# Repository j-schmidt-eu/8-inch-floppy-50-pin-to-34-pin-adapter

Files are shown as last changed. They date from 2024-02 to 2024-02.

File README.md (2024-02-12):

# 8-inch floppy drive - 50-pin to 34-pin adapter Rev. 2

> The 50-pin to 34-pin adapter can be used to adapt 8-inch floppy disk drives (using a 50-pin connector) to be controlled by 3.5-inch and 5.25-inch floppy controllers (using a 34-pin connector).

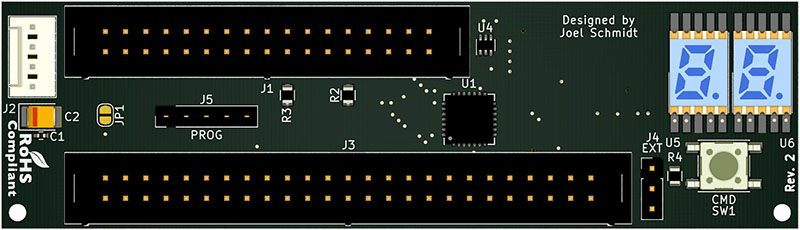
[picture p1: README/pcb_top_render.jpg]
PCB top render


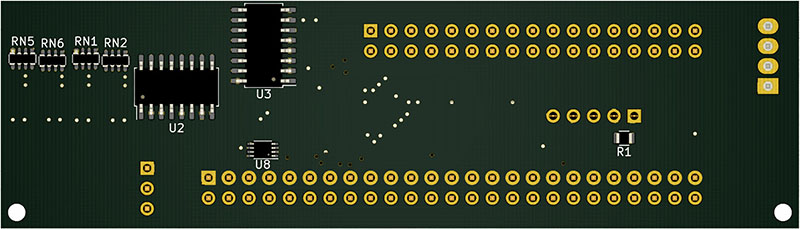
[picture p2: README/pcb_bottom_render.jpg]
PCB bottom render


## Table of Contents
- [Introduction](#Introduction)
- [Specifications](#Specifications)
- [Setup](#Setup)
- [Operation](#Operation)
- [Compatibility](#Compatibility)
- [Manufacturing](#Manufacturing)
- [Firmware](#Firmware)
- [FAQ](#FAQ)
- [Licensing](#Licensing)

## Introduction
Many 8-inch floppy drives use a 50-pin card-edge connector to link them to a controller. This is a problem, since modern floppy controllers use a 34-pin IDC connector.
To solve this problem an adapter is necessary that connects compatible signals and generates signals that are unique to the 8-inch floppy drives.
This project aims to provide the schematic, PCB design and firmware source code to build such an adapter.
All compatible signals are directly linked from the 50-pin connector to the 34-pin connector.
Other signals are generated with an onboard microcontroller.

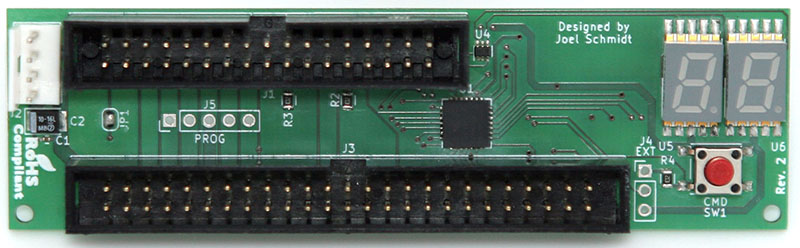
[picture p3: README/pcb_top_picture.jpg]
PCB top picture


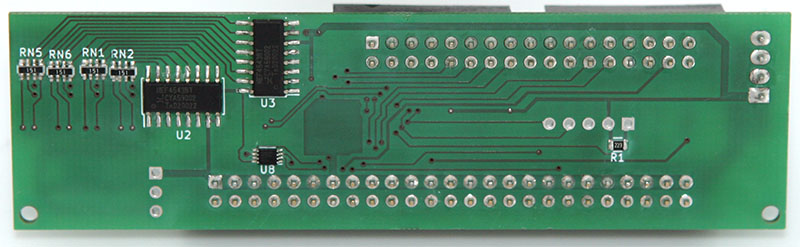
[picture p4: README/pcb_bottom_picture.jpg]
PCB bottom picture


## Specifications
- Power
  - Input voltage: 5V DC
  - Maximum input current: 750mA
  - Connector: 4-pin Berg/Amphenol
- Maximum number of drives per adapter: 2
- Maximum number of adapters per controller: 1
- Pass-through signals:

  | Direction | Name |
  | --------- | ---- |
  | IN        | Index |
  | OUT       | Drive select A |
  | OUT       | Drive select B |
  | OUT       | Direction |
  | OUT       | Step |
  | OUT       | Write data |
  | OUT       | Write gate |
  | IN        | Track 0 |
  | IN        | Write protect |
  | IN        | Read data |
  | OUT       | Side select |
- Generated signals:

  | Direction | Name | Signal source |
  | --------- | ---- | ------------- |
  | OUT       | TG43 (Track greater than 43) /<br>Reduce write current /<br>Filter switch | Determined by tracking the head position.<br>Multiple options available (e.g. control via external signal) |
  | OUT       | Head load | Derived from Motor enable signal.<br>Multiple options available (e.g. control via external signal) |
  | IN        | Ready | Derived from ready signal.<br>Can be disabled by removing a solder jumper bridge JP1 |

## Setup
The adapter can drive up to two drives.

### Floppy drive
A single drive should always be jumpered to be drive A.
The drive should have the termination resistors enabled/present.

A two drive setup should have one drive jumpered to be drive A and the other to be drive to be jumpered drive B.
The last drive (the drive connected at the end of the 50-pin ribbon cable) should have the termination resistors enabled/present, the other drive must have the termination resistors disabled/removed.

__**Important: Only one set of termination resistors must be enabled/present! Having more than one termination resistors enabled/present can damage the adapter and the floppy controller!**__

### Connections

#### Data
To connect the controller to the adapter, use a 34-pin ribbon cable (IDC socket connector to IDC socket connector).
It is recommended to connect the adapter after the twist in the ribbon cable. 

_Note: **When using straight cable without twist, drive A and drive B will be swapped on the controller side.**_

The drive(s) should be connected to the adapter with a 50-pin ribbon cable (IDC card edge connector to IDC socket connector).

#### Power
The adapter should be connected to a power supply via the 4 pin Berg/Amphenol connector (only the 5V line will be used). The pinout is ATX compatible.
Power for the floppy drive(s) should be supplied as described in the operations manual for that specific drive.

## Operation
To operate the adapter a single push button (command button) is present on the bottom right corner of the PCB.

_Note: **The button will be disabled when any drive is in use.**_

### Display
For status display and settings, a two-digit seven-segment display is present on the top right corner of the PCB.
A short press on the command button can be used to cycled between the following display modes:

| Mode | Dot status | Description | Range |
| ---- | ---- | --- | ----- |
| Track | Left: off<br>Right: on | Current head position | 0 ... 80 |
| Speed | Left: on (positive value) / blink (negative value)<br>Right: off | Percent deviation from nominal rotational speed | -9.9% ... 9.9% |
| Revision | Left: blink<br>Right: blink<br>Alternates between left and right | Software revision number | 1 ... 99 |
| Dark | Left: off<br>Right: off | Disables display | - |

### Settings
To edit the settings of the adapter the setup menu can be entered by pressing the command button for longer than two seconds.
When navigating the setup menu both dots will be lit.
A short press on the command button can be used to cycled between the menu items.
Item value editing can be enabled and disabled by pressing the command button for longer than two seconds.
During editing both dots will blink simultaneously.
A short press on the command button can be used to cycled between value.

To exit the setup menu, navigate to the Exit item and press the command button for longer than two seconds.

The following menu items are available (in listed order):

| Item | Display | Description | Values | Default |
| ---- | --- | --- | --- | --- |
| Default display mode | Left: 1<br>Right: value | Default display mode after adapter power up | 0: Track<br>1: Speed<br>2: Revision<br>3: Dark | 0: Track |
| Drive A<br>Maximum track number | Left/Right: value | Maximum track number that the drive can step to | 32 ... 80 | 76 |
| Drive A<br>TGxx signal | Left: 3<br>Right: value | Source for TG43 / reduce write current / filter signal | 0: Use thresholds<br>1: Always active<br>2: Always inactive<br>3: From external signal | 0: Use thresholds |
| Drive A<br>Head load signal | Left: 4<br>Right: value | Source for head load signal | 0: From [motor A enable]<br>1: Always active<br>2: Always inactive<br>3: From external signal | 0: From [motor A enable] |
| Drive A<br>TGxx write threshold | Left/Right: value | Track number threshold (greater or equal) for TGxx signal active when writing | 0 ... 99 | 44 |
| Drive A<br>TGxx read threshold | Left/Right: value | Track number threshold (greater or equal) for TGxx signal active when reading | 0 ... 99 | 99 |
| Drive B<br>Maximum track number | Left/Right: value | Maximum track number that the drive can step to | 32 ... 80 | 76 |
| Drive B<br>TGxx signal | Left: 8<br>Right: value | Source for TG43 / reduce write current / filter signal | 0: Use thresholds<br>1: Always active<br>2: Always inactive<br>3: From external signal | 0: Use thresholds |
| Drive B<br>Head load signal | Left: 9<br>Right: value | Source for head load signal | 0: From [motor B enable]<br>1: Always active<br>2: Always inactive<br>3: From external signal | 0: From [motor B enable] |
| Drive B<br>TGxx write threshold | Left/Right: value | Track number threshold (greater or equal) for TGxx signal active when writing | 0 ... 99 | 44 |
| Drive B<br>TGxx read threshold | Left/Right: value | Track number threshold (greater or equal) for TGxx signal active when reading | 0 ... 99 | 99 |
| Exit | Left/Right: dark | - | - | - |

_Note: **The external signal cannot distinguish between multiple signals, therefore it should only be assigned to a single signal.**_

The settings are permanently stored when exiting the setup menu.

## Compatibility
The following list shows some 8-inch floppy drive models and the respective settings that should be correct for them.

| Model | TGxx signal | TGxx write threshold | TGxx read threshold | Head load signal | Maximum track number<sup>1</sup> | Tested<sup>2</sup> |
| ----- | --- | --- | --- | --- | --- | --- |
| Mitsubishi M2896-63 | 0: Use thresholds <sup>4</sup> | 44 | 99 | 0: From [motor enable]  | 76(?) | ❓ |
| NEC FD1165 | 0: Use thresholds | 44 | 44 | 0: From [motor enable] | 76(?) | ❓ |
| Shugart SA800<br>Shugart SA801 | 0: Use thresholds <sup>3</sup> | 44 | 99 | 0: From [motor enable] <sup>4</sup> | 76(?) | ❓ |
| Shugart SA810<br>Shugart SA860 | 0: Use thresholds <sup>4</sup> | 44 | 99 | 0: From [motor enable] <sup>4</sup> | 76(?) | ❓ |
| Shugart SA850<br>Shugart SA851 | 0: Use thresholds <sup>4</sup> | 44 | 99 | 0: From [motor enable] <sup>4</sup> | 76(?) | ❓ |
| Tandon TM848-1E<br>Tandon TM848-2E | 0: Use thresholds <sup>4</sup> | 44 | 99 | 0: From [motor enable] <sup>4</sup> | 76(?) | ❓ |
| Y-E DATA YD-180 | 0: Use thresholds | 44 | 60 | 0: From [motor enable] <sup>4</sup> | 79 | ✅ |

<sup>1</sup> Actual seekable track number; track numbering starts at zero.<br>
<sup>2</sup> ✅: Settings have been successfully tested. ❓: Settings should be correct according to the manual, but haven't been tested yet.<br>
<sup>3</sup> Switching is done internally.<br>
<sup>4</sup> Switching is done internally by default; external switching is available optionally (see manual).

## Manufacturing
The schematics and PCB were designed using [KiCad](https://kicad-pcb.org/). The KiCad project is located in the [Schematics & PCB](Schematics%20&%20PCB) folder. 

### Schematic
[PDF](Schematics%20&%20PCB/50%20pin%20to%2034%20pin%20Floppy%20Adapter%20v2/50%20pin%20to%2034%20pin%20Floppy%20Adapter.pdf)

[PNG](Schematics%20&%20PCB/50%20pin%20to%2034%20pin%20Floppy%20Adapter%20v2/50%20pin%20to%2034%20pin%20Floppy%20Adapter.png)

### PCB Gerber files
[ZIP](Schematics%20&%20PCB/50%20pin%20to%2034%20pin%20Floppy%20Adapter%20v2/pcb.zip)

### PCB manufacturing
The board has a size of 100mm x 28.5mm, a minimum trace distance of 0.2mm and the minimal drill diameter is 0.4mm.
There are two layers and a total of 166 holes to drill. All holes, except for the two mounting holes, are plated.

If you are within the EU, you may want to consider choosing AISLER as your PCB manufacturer.

[PCB on AISLER](https://aisler.net/p/LBENFXQV)

### Bill of materials
| Reference | Component | Housing /<br>Footprint | Type | Quantity |
| --- | --- | --- | ---- | --- |
| C1 | Capacitor 100nF 10V | 0402 | Murata GRM155R61A104JA01D<sup>5</sup> | 1 |
| C2 | Tantalum Capacitor 10µF 6.3V  | B / EIA-3528-21 | Kemet T491B106K006AT<sup>5</sup>  | 1 |
| J1 | 34 pin box header | 2 x 17 x 2.54mm | Connfly DS1013-34SSIB1-B-0<sup>5</sup> | 1 |
| J2 | 4 pin Berg connector | 1 x 4 x 2.54mm | econ connect FK03PN<sup>5</sup> | 1 |
| J3 | 50 pin box header | 2 x 25 x 2.54mm | Connfly DS1013-50SSIB1-B-0<sup>5</sup> | 1 |
| ~~J4~~<sup>6</sup> | ~~3 pin header~~ | ~~1 x 3 x 2.54mm~~ | ~~Connfly DS1021-1*3SF1-1~~<sup>5</sup> | ~~1~~ |
| J5 | 5 pin socket | 1 x 5 x 2.54mm | Connfly DS1023-1*5S21<sup>5</sup> | 1 |
| R2 | Resistor 22kOhm 1/8W 5% | 0805 | Vishay CRCW080522K0FKEA<sup>5</sup> | 1 |
| R1, R3-R4 | Resistor 1kOhm 1/8W 5% | 0805 | Vishay CRCW08051K00FKEA<sup>5</sup> | 3 |
| RN1-RN2, RN5-RN6 | Resistor array 150Ohm 1/16W 5% | 4 x 0603 (1206) convex | Panasonic EXB38V151JV<sup>5</sup> | 4 |
| SW1 | SMD Push button 6mm x 6mm | 9.5mm x 5.8mm | C&K PTS645SK50SMTR92LFS<sup>5</sup> | 1 |
| U1 | PIC18 MCU | QFN-28, 6mm x 6mm, pitch 0.65mm | Microchip PIC18F26K22-I/ML | 1 |
| U2-U3 | BCD to 7-segment decoder | SOP-16, 4.55mm x 10.3mm, pitch 1.27mm | NXP HEF4543B | 2 |
| U4 | Dual buffer | SOT-363 / SC-70-6 | ON Semi NC7WZ16P6X | 1 |
| U5-U6 | Seven segment display | 7mm x 15mm | Kingbright KCSA03-101 | 2 |
| U8 | Dual three-state buffer | VSSOP-8, 2.3mm x 2mm, pitch 0.5mm | ON Semi NC7WZ125K8X | 1 |

<sup>5</sup> Suggestion; Other types may be used. <br>
<sup>6</sup> Not populated; Pin header may be placed, when needed.

### PCB component placement
When soldering the components to the PCB, it is recommended to place them in the following order:
1. Bottom side, hot air: RN1-RN2, RN5-RN6, R2, U2, U3, U8
2. Top side, hot air: C1, C2, R1, R3, R4, U4, U1
3. Top side, soldering iron: U5, U6, SW1, J1, J3, J5, J2
4. Do not populate: J4 (place pin header when needed)

## Firmware
The software for the microcontroller was designed in [MPLAB X IDE](https://www.microchip.com/mplab/mplab-x-ide).
It is written in C and compiled with the [MPLAB XC8 compiler](https://www.microchip.com/mplab/compilers).
A programming adapter is required to transfer the firmware into the microcontroller. The programming socket J5 is designed to match the pinout of the [MPLAB PICkit 4](https://www.microchip.com/developmenttools/ProductDetails/PG164140) (and older) programmers.
The MPLAB X IDE project is located in the [Firmware](Firmware) folder. 

## FAQ
##### My drive is not listed in the compatibility list, will it work?
>**Check the manual of your drive to see if it needs any additional signals like TG43 and Head load.
If so, check if one of the available options matches the behavior required by the drive. When that is the case, the drive will very likely work.**

## Licensing
This project is licensed under the [CC BY-NC-ND 4.0 license](LICENSE).



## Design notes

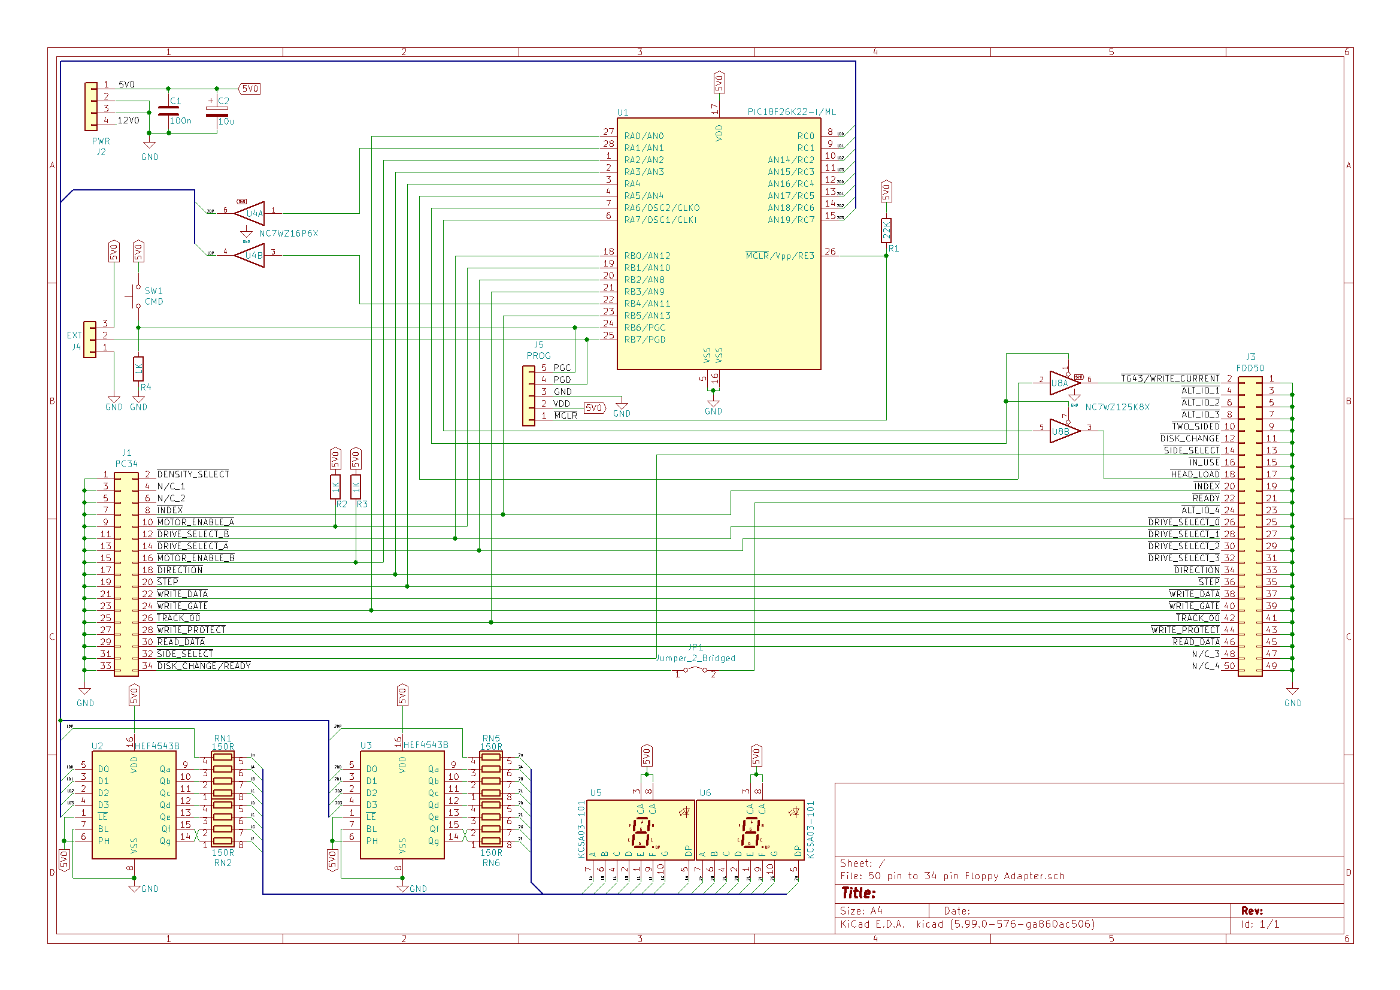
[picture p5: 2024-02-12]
Schematics & PCB/50 pin to 34 pin Floppy Adapter v2/50 pin to 34 pin Floppy Adapter.png

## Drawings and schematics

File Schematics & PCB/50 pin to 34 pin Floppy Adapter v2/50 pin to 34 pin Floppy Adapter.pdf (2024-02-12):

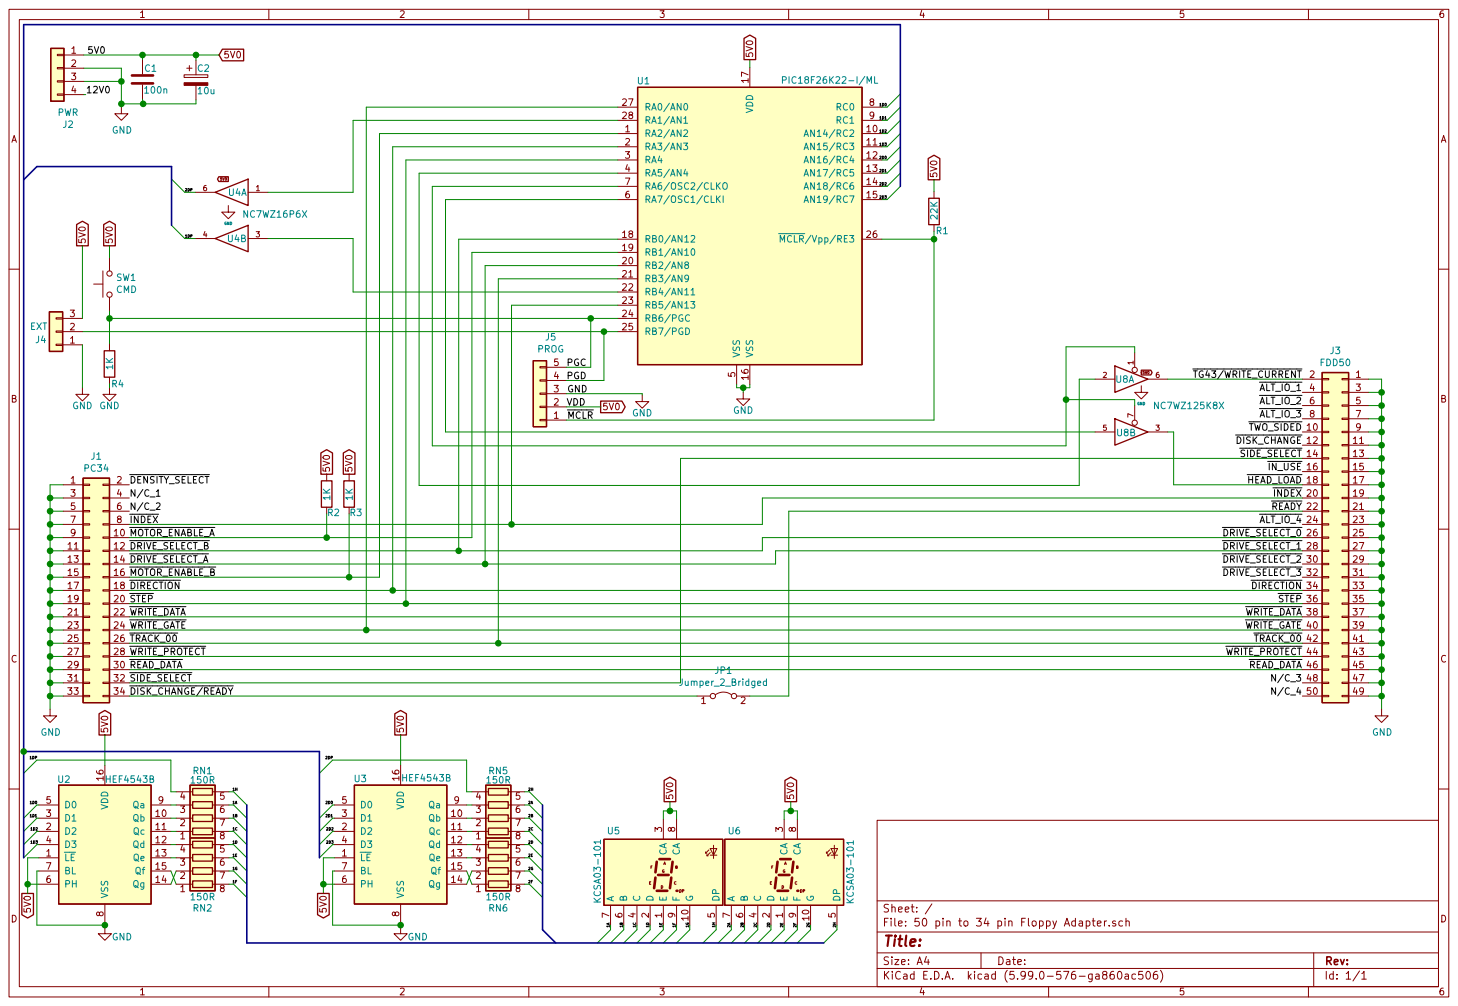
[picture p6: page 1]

13 | 14 | INDEX N/C_4 WRITE_GATE WRITE_DATA DIRECTION 30 32 34 | 29

22 | 21
24 26 | 23

19 | 20 | READ_DATA WRITE_PROTECT DRIVE_SELECT_3 36 | 35

21 | 22 | 38 | 37
23 | 24 | 40 | 39
25 | 26 | 42 | 41
27 | 28 | 44 | 43
29 | 30 READ_DATA | 46 | 45
31 | 32 | | 47
33 | 34 | | 49

8 Qa 9 Qb 10 Qc 11 Qd 12 Qe 13 Qg 14 Qf 15 VDD

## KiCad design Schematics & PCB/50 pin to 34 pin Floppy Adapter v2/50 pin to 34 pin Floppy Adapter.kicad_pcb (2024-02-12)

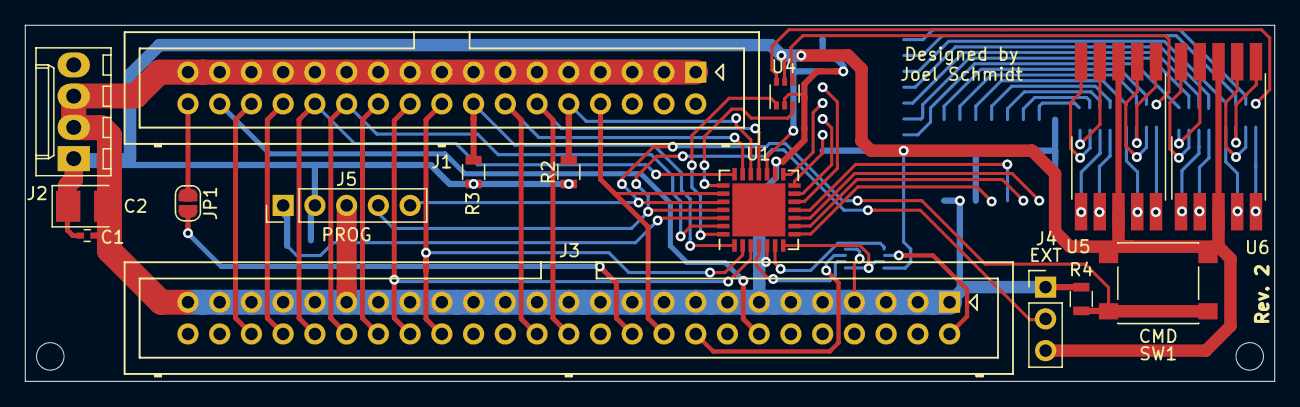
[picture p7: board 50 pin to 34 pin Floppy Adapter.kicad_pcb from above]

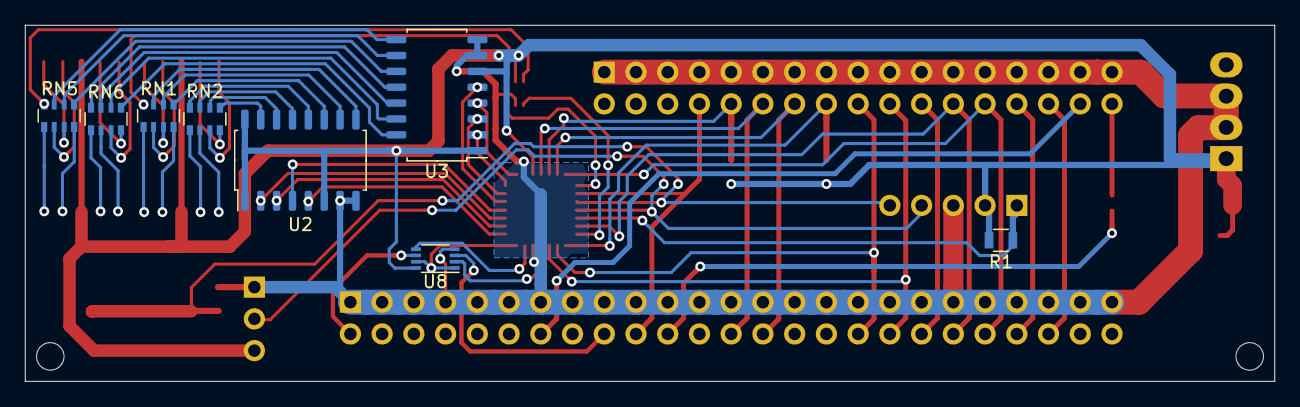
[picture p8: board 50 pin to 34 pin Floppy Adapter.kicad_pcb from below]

Board: 2 copper layers, 100.0 x 28.5 mm, 24 parts (8 on the bottom side), 67 nets.

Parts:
C1: 100n; C_0402
C2: 10u; CP_Tantalum_Case-B_EIA-3528-21_Reflow
J1: PC34; Multicomp_MC9A12-3434_2x17x2.54mm_Straight
J2: PWR; TE_171825-4x2.50mm_Straight
J3: FDD50; Multicomp_MC9A12-5034_2x25x2.54mm_Straight
J4: EXT; Pin_Header_Straight_1x03_Pitch2.54mm
J5: PROG; Pin_Header_Straight_1x05_Pitch2.54mm
JP1: Jumper_2_Bridged; SolderJumper-2_P1.3mm_Open_RoundedPad1.0x1.5mm
R1: 22K; R_0805
R2, R3, R4: 1K; R_0805
RN1, RN2, RN5, RN6: 150R; R_Array_Convex_4x0603
SW1: CMD; SW_SPST_PTS645
U1: PIC18F26K22-I/ML; QFN-28-1EP_6x6mm_Pitch0.65mm
U2, U3: HEF4543B; SOP-16_4.55x10.3mm_P1.27mm
U4: NC7WZ16P6X; SOT-363_SC-70-6
U5, U6: KCSA03-101
U8: NC7WZ125K8X; VSSOP-8_2.3x2mm_Pitch0.5mm

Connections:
5V0: C1.1, C2.1, J2.1, J4.3, J5.2, R1.2, R2.1, R3.1, SW1.2, U1.17, U2.1, U2.6, U2.16, U3.1, U3.6, U3.16, U4.5, U5.3, U5.8, U6.3, U6.8, U8.8
/1A: RN1.6, U5.7
/1B: RN1.7, U5.6
/1C: RN1.8, U5.4
/1D: RN2.5, U5.2
/1D0: U1.8, U2.5
/1D1: U1.9, U2.3
/1D2: U1.10, U2.2
/1D3: U1.11, U2.4
/1DP: RN1.4, U4.4
/1E: RN2.6, U5.1
/1F: RN2.8, U5.9
/1G: RN2.7, U5.10
/1H: RN1.5, U5.5
/2A: RN5.6, U6.7
/2B: RN5.7, U6.6
/2C: RN5.8, U6.4
/2D: RN6.5, U6.2
/2D0: U1.12, U3.5
/2D1: U1.13, U3.3
/2D2: U1.14, U3.2
/2D3: U1.15, U3.4
/2DP: RN5.4, U4.6
/2E: RN6.6, U6.1
/2F: RN6.8, U6.9
/2G: RN6.7, U6.10
/2H: RN5.5, U6.5
/PGC: J5.5, R4.1, SW1.1, U1.24
/PGD: J4.2, J5.4, U1.25
/~DIRECTION: J1.18, J3.34, U1.2
/~DISK_CHANGE/READY: J1.34, JP1.1
/~DRIVE_SELECT_0: J1.12, J3.26, U1.18
/~DRIVE_SELECT_1: J1.14, J3.28, U1.20
/~HEAD_LOAD: J3.18, U8.3
/~INDEX: J1.8, J3.20, U1.23
/~MCLR: J5.1, R1.1, U1.26
/~MOTOR_ENABLE_A: J1.10, R2.2, U1.19
/~MOTOR_ENABLE_B: J1.16, R3.2, U1.1
/~READY: J3.22, JP1.2
/~READ_DATA: J1.30, J3.46
/~SIDE_SELECT: J1.32, J3.14
/~STEP: J1.20, J3.36, U1.3
/~TG43/WRITE_CURRENT: J3.2, U8.6
/~TRACK_00: J1.26, J3.42, U1.21
/~WRITE_DATA: J1.22, J3.38
/~WRITE_GATE: J1.24, J3.40, U1.27
/~WRITE_PROTECT: J1.28, J3.44
GND: C1.2, C2.2, J1.1, J1.3, J1.5, J1.7, J1.9, J1.11, J1.13, J1.15, J1.17, J1.19, J1.21, J1.23, J1.25, J1.27, J1.29, J1.31, J1.33, J2.2, J2.3, J3.1, J3.3, J3.5, J3.7, J3.9, J3.11, J3.13, J3.15, J3.17, J3.19, J3.21, J3.23, J3.25, J3.27, J3.29, J3.31, J3.33, J3.35, J3.37, J3.39, J3.41, J3.43, J3.45, J3.47, J3.49, J4.1, J5.3, R4.2, U1.5, U1.16, U2.7, U2.8, U3.7, U3.8, U4.2, U8.4
unnamed: RN1.1, U2.11
unnamed: RN1.2, U2.10
unnamed: RN1.3, U2.9
unnamed: RN2.1, U2.15
unnamed: RN2.2, U2.14
unnamed: RN2.3, U2.13
unnamed: RN2.4, U2.12
unnamed: RN5.1, U3.11
unnamed: RN5.2, U3.10
unnamed: RN5.3, U3.9
unnamed: RN6.1, U3.15
unnamed: RN6.2, U3.14
unnamed: RN6.3, U3.13
unnamed: RN6.4, U3.12
unnamed: U1.4, U8.2
unnamed: U1.6, U8.5
unnamed: U1.7, U8.1, U8.7
unnamed: U1.22, U4.3
unnamed: U1.28, U4.1

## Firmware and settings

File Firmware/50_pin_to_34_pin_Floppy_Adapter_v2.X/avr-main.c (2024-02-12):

#include "xc8_header.h"

#define REVISON 01

#define DEBOUNCE_TIME 25
#define LONG_PRESS_TIME 2000

#define MOTOR_ENABLE_A PORTBbits.RB1
#define MOTOR_ENABLE_B PORTAbits.RA2
#define DIRECTION PORTAbits.RA3
#define STEP PORTAbits.RA4
#define HEAD_LOAD PORTAbits.RA7
#define TG43_WRITE_CURRENT PORTAbits.RA5
#define DEVICE_SELECT_0 PORTBbits.RB0
#define DEVICE_SELECT_1 PORTBbits.RB2
#define TRACK_0 PORTBbits.RB3
#define WRITE_GATE PORTAbits.RA0
#define INDEX PORTBbits.RB5
#define CMD_SWITCH PORTBbits.RB6
#define EXT_SIGNAL PORTBbits.RB7

#define OUTPUT_ENABLE PORTAbits.RA6

#define _7SEG_1_DOT PORTBbits.RB4
#define _7SEG_2_DOT PORTAbits.RA1

#define TG_FIRST TG_UseThresholds
enum TGXXMode
{
    TG_UseThresholds,
    TG_AlwaysActive,
    TG_AlwaysInactive,
    TG_FromExternalSignal
};
#define TG_LAST TG_FromExternalSignal

#define HL_FIRST HL_FromMotorEnable
enum HeadLoadMode
{
    HL_FromMotorEnable,
    HL_AlwaysActive,
    HL_AlwaysInactive,
    HL_FromExternalSignal
};
#define HL_LAST HL_FromExternalSignal

#define D_FIRST D_Track
enum DisplayMode
{
    D_Track,
    D_Speed,
    D_Revision,
    D_Dark
};
#define D_LAST D_Dark

#define M_FIRST M_Display
enum MenuMode
{
    M_Hidden,
    M_Display,
    M_MaxTrack_A,
    M_TGXX_A,
    M_HeadLoad_A,
    M_TGWriteTheshold_A,
    M_TGReadTheshold_A,
    M_MaxTrack_B,
    M_TGXX_B,
    M_HeadLoad_B,
    M_TGWriteTheshold_B,
    M_TGReadTheshold_B,
    M_Exit
};
#define M_LAST M_Exit

struct DriveParams {
    // Track counting
    volatile int_fast8_t track;
    volatile int_fast8_t maxTrack;
    
    // RPM
    volatile int_fast8_t speedDeviationPercentTenths;
    
    // Modes
    volatile enum HeadLoadMode headLoadMode;
    volatile enum TGXXMode tgXXMode;
    
    // TGXX
    volatile int_fast8_t tgWriteThreshold;
    volatile int_fast8_t tgReadThreshold;
};

uint_fast8_t EepromRead(uint_fast16_t address);
void EepromWrite(uint_fast16_t address, uint_fast8_t data);

volatile __bit blink = 0;

volatile uint_fast16_t counter6000Hz = 0;
volatile uint_fast16_t counter1000Hz = 0;

#define REFERENCE_SPEED_COUNT_6000HZ 1004
#define REFERENCE_SPEED_COUNT_6000HZ_1_Percent 10
#define REFERENCE_SPEED_COUNT_6000HZ_9_9_Percent 99

volatile struct DriveParams driveParams_A;
volatile struct DriveParams driveParams_B;
volatile struct DriveParams * driveParams = &driveParams_A;

__EEPROM_DATA(0, 76, 0, 0, 44, 99, 76, 0);
__EEPROM_DATA(0, 44, 99,       0,0,0,0,0);

int main(void)
{
    INTCONbits.PEIE = 0;
    INTCONbits.GIE = 0;
    RCONbits.IPEN = 1;
    
    // Set system to 64MHz
    OSCCON = 0b01110000;
    OSCTUNE = 0b01000000;
    
    // Disable Timer 0
    INTCONbits.T0IE = 0;
    INTCON2bits.TMR0IP = 0;
    T0CON = 0x00;
    
    // Disable all analog
    ANSELA = 0x00;
    ANSELB = 0x00;
    ANSELC = 0x00;

    TRISA = 0b01011101; // RA0: IN, RA1: OUT, RA2-4: IN, RA5: OUT, RA6: IN, RA7: OUT
    TRISB = 0b11101111; // RB0-3: IN, RB4: OUT, RB5-7: IN
    TRISC = 0b00000000; // RC0-7: OUT

    // Reset outputs
    PORTA &= 0b11111111;

    // Reset 7 segment display
    PORTC = 0x00;
    _7SEG_1_DOT = 0;
    _7SEG_2_DOT = 0;
    
    // Enable Timer 1
    PIE1bits.TMR1IE = 0;
    IPR1bits.TMR1IP = 0;
    T1CON = 0b00000011;
    
    // Enable Timer 2
    IPR1bits.TMR2IP = 0;
    PR2 = 166 - 1;
    T2CON = 0b01111100;
    
    // Enable Timer 4
    IPR5bits.TMR4IP = 0;
    PR4 = 250 - 1;
    T4CON = 0b01111100;
        
    // Capture
    CCPTMRS0 = 0b00000000;
    CCPTMRS1 = 0b00000000;
    
    // Capture 2 (RB3) -> TRACK_0
    IPR2bits.CCP2IP = 1;
    CCP2CON = 0b00000100;
    
    // Capture 3 (RB5) -> INDEX
    IPR4bits.CCP3IP = 0;
    CCP3CON = 0b00000100;
    
    // Capture 5 (RA4) -> STEP
    IPR4bits.CCP5IP = 1;
    CCP5CON = 0b00000100;
    
    // Interrupt 0 (RB0) -> DEVICE_SELECT_0
    INTCON2bits.INTEDG0 = 0;
    // INT0 is always high priority
    
    // Interrupt 2 (RB2) -> DEVICE_SELECT_1
    INTCON2bits.INTEDG2 = 0;
    INTCON3bits.INT2IP = 1;
    
    
    // Inputs
    static __bit externalSignal = 0;
    static __bit cmdSwitch = 0;

    // Outputs
    static __bit headLoad = 0;
    static __bit tg43 = 0;
    static uint_fast8_t bcd1 = 0;
    static uint_fast8_t bcd2 = 0;
    static __bit dot1 = 0;
    static __bit dot2 = 0;

    // Variables
    static uint_fast16_t cmdSwitchStartCount = 0;
    static __bit cmdSwitchLast = 0;
    static __bit cmdSwitchShort = 0;
    static __bit cmdSwitchLong = 0;
    static __bit menuEdit = 0;
    static int_fast8_t speed = 0;
    
    static enum MenuMode menuMode = M_Hidden;
    static enum DisplayMode startDisplayMode = D_FIRST;
    static enum DisplayMode displayMode = D_FIRST;
    
    // EEPROM
    static volatile uint_fast8_t eepromValue = 0;
    static uint_fast16_t eepromAddress = 0;
    
    // Set defaults
    driveParams_A.track = 0;
    driveParams_A.maxTrack = 76;
    driveParams_A.speedDeviationPercentTenths = 0;
    driveParams_A.headLoadMode = HL_FIRST;
    driveParams_A.tgXXMode = TG_FIRST;
    driveParams_A.tgWriteThreshold = 44;
    driveParams_A.tgReadThreshold = 99;
    driveParams_B.track = 0;
    driveParams_B.maxTrack = 76;
    driveParams_B.speedDeviationPercentTenths = 0;
    driveParams_B.headLoadMode = HL_FIRST;
    driveParams_B.tgXXMode = TG_FIRST;
    driveParams_B.tgWriteThreshold = 44;
    driveParams_B.tgReadThreshold = 99;
    
    // Read values to EEPROM
    
    // Global
    eepromValue = EepromRead(eepromAddress++);
    startDisplayMode = (enum DisplayMode)eepromValue;
    
    // Drive A
    eepromValue = EepromRead(eepromAddress++);
    driveParams_A.maxTrack = (int_fast8_t)eepromValue;
    
    eepromValue = EepromRead(eepromAddress++);
    driveParams_A.tgXXMode = (enum TGXXMode)eepromValue;
            
    eepromValue = EepromRead(eepromAddress++);
    driveParams_A.headLoadMode = (enum HeadLoadMode)eepromValue;
    
    eepromValue = EepromRead(eepromAddress++);
    driveParams_A.tgWriteThreshold = (int_fast8_t)eepromValue;
    
    eepromValue = EepromRead(eepromAddress++);
    driveParams_A.tgReadThreshold = (int_fast8_t)eepromValue;

    // Drive B
    eepromValue = EepromRead(eepromAddress++);
    driveParams_B.maxTrack = (int_fast8_t)eepromValue;
    
    eepromValue = EepromRead(eepromAddress++);
    driveParams_B.tgXXMode = (enum TGXXMode)eepromValue;
            
    eepromValue = EepromRead(eepromAddress++);
    driveParams_B.headLoadMode = (enum HeadLoadMode)eepromValue;
    
    eepromValue = EepromRead(eepromAddress++);
    driveParams_B.tgWriteThreshold = (int_fast8_t)eepromValue;
    
    eepromValue = EepromRead(eepromAddress++);
    driveParams_B.tgReadThreshold = (int_fast8_t)eepromValue;

    displayMode = startDisplayMode;

    INTCONbits.PEIE = 1;
    INTCONbits.GIE = 1;
    
    PIE1bits.TMR2IE = 1;
    PIE5bits.TMR4IE = 1;
    
    PIE2bits.CCP2IE = 1;
    PIE4bits.CCP3IE = 1;
    PIE4bits.CCP4IE = 1;
    PIE4bits.CCP5IE = 1;
    
    INTCONbits.INT0IE = 1;
    INTCON3bits.INT2IE = 1;
    
    while (1)
    {
        if (!DEVICE_SELECT_0 || !DEVICE_SELECT_1)
        {
            externalSignal = EXT_SIGNAL;

            // TG43 to FDD
            {
                switch (driveParams->tgXXMode)
                {
                case TG_UseThresholds:
                    if(!WRITE_GATE)
                        tg43 = (driveParams->track >= driveParams->tgWriteThreshold);
                    else
                        tg43 = (driveParams->track >= driveParams->tgReadThreshold);
                    break;
                case TG_AlwaysActive:
                    tg43 = 1;
                    break;
                case TG_AlwaysInactive:
                    tg43 = 0;
                    break;
                case TG_FromExternalSignal:
                    tg43 = externalSignal;
                    break;
                }
                TG43_WRITE_CURRENT = !tg43;
            }

            // Head load to FDD
            {
                switch (driveParams->headLoadMode)
                {
                case HL_FromMotorEnable:
                    if(!DEVICE_SELECT_0)
                        headLoad = !MOTOR_ENABLE_A;
                    else
                        headLoad = !MOTOR_ENABLE_B;
                    break;
                case HL_AlwaysActive:
                    headLoad = 1;
                    break;
                case HL_AlwaysInactive:
                    headLoad = 0;
                    break;
                case HL_FromExternalSignal:
                    headLoad = externalSignal;
                    break;
                }
                HEAD_LOAD = !headLoad;
            }
            
            OUTPUT_ENABLE = 1;
        }
        else
        {
            OUTPUT_ENABLE = 0;
            
            HEAD_LOAD = 1;
            TG43_WRITE_CURRENT = 1;
            
            // Command button
            {
                cmdSwitch = CMD_SWITCH;

                if (cmdSwitch)
                {
                    if (!cmdSwitchLast)
                    {
                        cmdSwitchStartCount = counter1000Hz;

                        cmdSwitchLast = 1;
                    }
                    else
                    {
                        if(!cmdSwitchLong)
                        {
                            uint_fast16_t counts = counter1000Hz - cmdSwitchStartCount;
                            if(counts >= LONG_PRESS_TIME)
                            {
                                cmdSwitchShort = 0;
                                cmdSwitchLong = 1;
                            }
                            else if(!cmdSwitchShort && counts >= DEBOUNCE_TIME)
                            {
                                cmdSwitchShort = 1;
                            }
                        }
                    }
                }
            }

            // Process commands
            {
                if (!cmdSwitch && cmdSwitchLast)
                {
                    if (cmdSwitchLong)
                    {
                        if (menuMode == M_Hidden)
                        {
                            menuMode = M_FIRST;
                        }
                        else if (menuMode == M_Exit)
                        {
                            menuMode = M_Hidden;
                        }
                        else
                        {
                            menuEdit = !menuEdit;
                            
                            if(!menuEdit)
                            {
                                // Save values to EEPROM

                                eepromAddress = 0x00;
                                
                                eepromValue = (uint_fast8_t)startDisplayMode;
                                EepromWrite(eepromAddress++, eepromValue);
                                
                                eepromValue = (uint_fast8_t)driveParams_A.maxTrack;
                                EepromWrite(eepromAddress++, eepromValue);
                                
                                eepromValue = (uint_fast8_t)driveParams_A.tgXXMode;
                                EepromWrite(eepromAddress++, eepromValue);

                                eepromValue = (uint_fast8_t)driveParams_A.headLoadMode;
                                EepromWrite(eepromAddress++, eepromValue);

                                eepromValue = (uint_fast8_t)driveParams_A.tgWriteThreshold;
                                EepromWrite(eepromAddress++, eepromValue);
                                
                                eepromValue = (uint_fast8_t)driveParams_A.tgReadThreshold;
                                EepromWrite(eepromAddress++, eepromValue);
                                
                                eepromValue = (uint_fast8_t)driveParams_B.maxTrack;
                                EepromWrite(eepromAddress++, eepromValue);
                                
                                eepromValue = (uint_fast8_t)driveParams_B.tgXXMode;
                                EepromWrite(eepromAddress++, eepromValue);

                                eepromValue = (uint_fast8_t)driveParams_B.headLoadMode;
                                EepromWrite(eepromAddress++, eepromValue);

                                eepromValue = (uint_fast8_t)driveParams_B.tgWriteThreshold;
                                EepromWrite(eepromAddress++, eepromValue);
                                
                                eepromValue = (uint_fast8_t)driveParams_B.tgReadThreshold;
                                EepromWrite(eepromAddress++, eepromValue);
                            }
                        }

                        cmdSwitchLong = 0;
                    }
                    else if (cmdSwitchShort)
                    {
                        if (menuMode != M_Hidden)
                        {
                            if (!menuEdit)
                            {
                                if(menuMode == M_LAST)
                                    menuMode = M_FIRST;
                                else
                                    menuMode++;
                            }
                            else
                            {
                                switch(menuMode)
                                {
                                case M_Display:
                                    if(startDisplayMode == D_LAST)
                                        startDisplayMode = D_FIRST;
                                    else
                                        startDisplayMode++;
                                    break;
                                case M_MaxTrack_A:
                                    if(driveParams_A.maxTrack == 80)
                                        driveParams_A.maxTrack = 32;
                                    else
                                        driveParams_A.maxTrack++;
                                    break;
                                case M_TGXX_A:
                                    if(driveParams_A.tgXXMode == TG_LAST)
                                        driveParams_A.tgXXMode = TG_FIRST;
                                    else
                                        driveParams_A.tgXXMode++;
                                    break;
                                case M_HeadLoad_A:
                                    if(driveParams_A.headLoadMode == HL_LAST)
                                        driveParams_A.headLoadMode = HL_FIRST;
                                    else
                                        driveParams_A.headLoadMode++;
                                    break;
                                case M_TGWriteTheshold_A:
                                    if(driveParams_A.tgWriteThreshold == 99)
                                        driveParams_A.tgWriteThreshold = 0;
                                    else
                                        driveParams_A.tgWriteThreshold++;
                                    break;
                                case M_TGReadTheshold_A:
                                    if(driveParams_A.tgReadThreshold == 99)
                                        driveParams_A.tgReadThreshold = 0;
                                    else
                                        driveParams_A.tgReadThreshold++;
                                    break;
                                case M_MaxTrack_B:
                                    if(driveParams_B.maxTrack == 80)
                                        driveParams_B.maxTrack = 32;
                                    else
                                        driveParams_B.maxTrack++;
                                    break;
                                case M_TGXX_B:
                                    if(driveParams_B.tgXXMode == TG_LAST)
                                        driveParams_B.tgXXMode = TG_FIRST;
                                    else
                                        driveParams_B.tgXXMode++;
                                    break;
                                case M_HeadLoad_B:
                                    if(driveParams_B.headLoadMode == HL_LAST)
                                        driveParams_B.headLoadMode = HL_FIRST;
                                    else
                                        driveParams_B.headLoadMode++;
                                    break;
                                case M_TGWriteTheshold_B:
                                    if(driveParams_B.tgWriteThreshold == 99)
                                        driveParams_B.tgWriteThreshold = 0;
                                    else
                                        driveParams_B.tgWriteThreshold++;
                                    break;
                                case M_TGReadTheshold_B:
                                    if(driveParams_B.tgReadThreshold == 99)
                                        driveParams_B.tgReadThreshold = 0;
                                    else
                                        driveParams_B.tgReadThreshold++;
                                    break;
                                default:
                                    break;
                                }
                            }
                        }
                        else
                        {
                            if (displayMode == D_LAST)
                                displayMode = D_FIRST;
                            else
                                displayMode++;
                        }

                        cmdSwitchShort = 0;
                    }

                    cmdSwitchLast = 0;
                }
            }
        }

        // Display
        {
            if (menuMode != M_Hidden)
            {
                bcd1 = (uint_fast8_t) menuMode;

                switch(menuMode)
                {
                case M_Display:
                    bcd2 = (uint_fast8_t) startDisplayMode;
                    break;
                case M_MaxTrack_A:
                    bcd1 = (uint_fast8_t) (driveParams_A.maxTrack / 10);
                    bcd2 = (uint_fast8_t) (driveParams_A.maxTrack % 10);
                    break;
                case M_TGXX_A:
                    bcd2 = (uint_fast8_t) driveParams_A.tgXXMode;
                    break;
                case M_HeadLoad_A:
                    bcd2 = (uint_fast8_t) driveParams_A.headLoadMode;
                    break;
                case M_TGWriteTheshold_A:
                    bcd1 = (uint_fast8_t) (driveParams_A.tgWriteThreshold / 10);
                    bcd2 = (uint_fast8_t) (driveParams_A.tgWriteThreshold % 10);
                    break;
                case M_TGReadTheshold_A:
                    bcd1 = (uint_fast8_t) (driveParams_A.tgReadThreshold / 10);
                    bcd2 = (uint_fast8_t) (driveParams_A.tgReadThreshold % 10);
                    break;
                case M_MaxTrack_B:
                    bcd1 = (uint_fast8_t) (driveParams_B.maxTrack / 10);
                    bcd2 = (uint_fast8_t) (driveParams_B.maxTrack % 10);
                    break;
                case M_TGXX_B:
                    bcd2 = (uint_fast8_t) driveParams_B.tgXXMode;
                    break;
                case M_HeadLoad_B:
                    bcd2 = (uint_fast8_t) driveParams_B.headLoadMode;
                    break;
                case M_TGWriteTheshold_B:
                    bcd1 = (uint_fast8_t) (driveParams_B.tgWriteThreshold / 10);
                    bcd2 = (uint_fast8_t) (driveParams_B.tgWriteThreshold % 10);
                    break;
                case M_TGReadTheshold_B:
                    bcd1 = (uint_fast8_t) (driveParams_B.tgReadThreshold / 10);
                    bcd2 = (uint_fast8_t) (driveParams_B.tgReadThreshold % 10);
                    break;
                default:
                    bcd2 = 0xFF;
                    break;
                }

                if (menuEdit ^ cmdSwitchLong)
                {
                    dot1 = dot2 = blink;
                }
                else
                {
                    dot1 = dot2 = 1;
                }
            }
            else
            {
                switch (displayMode)
                {
                case D_Track:
                    bcd1 = (uint_fast8_t) (driveParams->track / 10);
                    bcd2 = (uint_fast8_t) (driveParams->track % 10);
                    dot1 = 0;
                    dot2 = 1;
                    break;

                case D_Speed:
                    speed = driveParams->speedDeviationPercentTenths;
                    if(speed < 0)
                    {
                        dot1 = blink;
                        speed = -speed;
                    }
                    else
                    {
                        dot1 = 1;
                    }
                    bcd1 = (uint_fast8_t) (speed / 10);
                    bcd2 = (uint_fast8_t) (speed % 10);
                    dot2 = 0;
                    break;

                case D_Revision:
                    bcd1 = (uint_fast8_t) (REVISON / 10);
                    bcd2 = (uint_fast8_t) (REVISON % 10);
                    dot1 = blink;
                    dot2 = !blink;
                    break;

                case D_Dark:
                    bcd2 = bcd1 = 0xFF;
                    dot2 = dot1 = 0;
                    break;
                }
            }

            PORTC = (bcd1 & 0xF) | ((bcd2 << 4) & 0xF0);
            _7SEG_1_DOT = !dot1;
            _7SEG_2_DOT = !dot2;
        }
    }
}
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

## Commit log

2024-02-12 PCB, firmware and readme for revision 1.
    [50 pin to 34 pin Floppy Adapter-B_Adhes.gbr, 50 pin to 34 pin Floppy Adapter-B_CrtYd.gbr, 50 pin to 34 pin Floppy Adapter-B_Cu.gbr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]
2024-02-12 PCB, firmware and readme for revision 2.
    [50 pin to 34 pin Floppy Adapter-B_Adhes.gbr, 50 pin to 34 pin Floppy Adapter-B_CrtYd.gbr, 50 pin to 34 pin Floppy Adapter-B_Cu.gbr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]
